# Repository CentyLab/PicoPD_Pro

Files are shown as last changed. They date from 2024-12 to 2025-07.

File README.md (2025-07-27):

# PicoPD Pro
Pico PD Pro is a development board for USB Power Delivery development with Raspberry Pi Pico footprint. The board can help you negotiate voltage from USB PD 3.1 with PPS (programable power supply) and AVS (Adjustable Voltage Supply) up to 5A of current at 30V max. The board feature input current/voltage/temperture reading as well as power switch to cut of the current to external devices. The 30V voltage limit is the max input voltage of the AP33772S IC.

# Quick links
[AP33772S Cpp Library](https://github.com/CentyLab/AP33772S-Cpp)

[AP33772S CircuitPython Library](https://github.com/hansendc/CircuitPython_AP33772s/) -> Big thanks to [@hansendc](https://github.com/hansendc)

[PicoPD Pro Pinout](#picopd-pro-pinout)

[Setup for AP33772S objects](#setup-for-AP33772S-objects)

[Basic AP33772S functions](#basic-ap33772S-functions)

[Important note](#important-note)

[Arduino IDE setup](#arduino-ide-setup)

[VSCode PlatformIO setup](#vscode-platformio-setup)

[Enable Serial print for debugging](#enable-serial-debug)

# PicoPD Pro Pinout
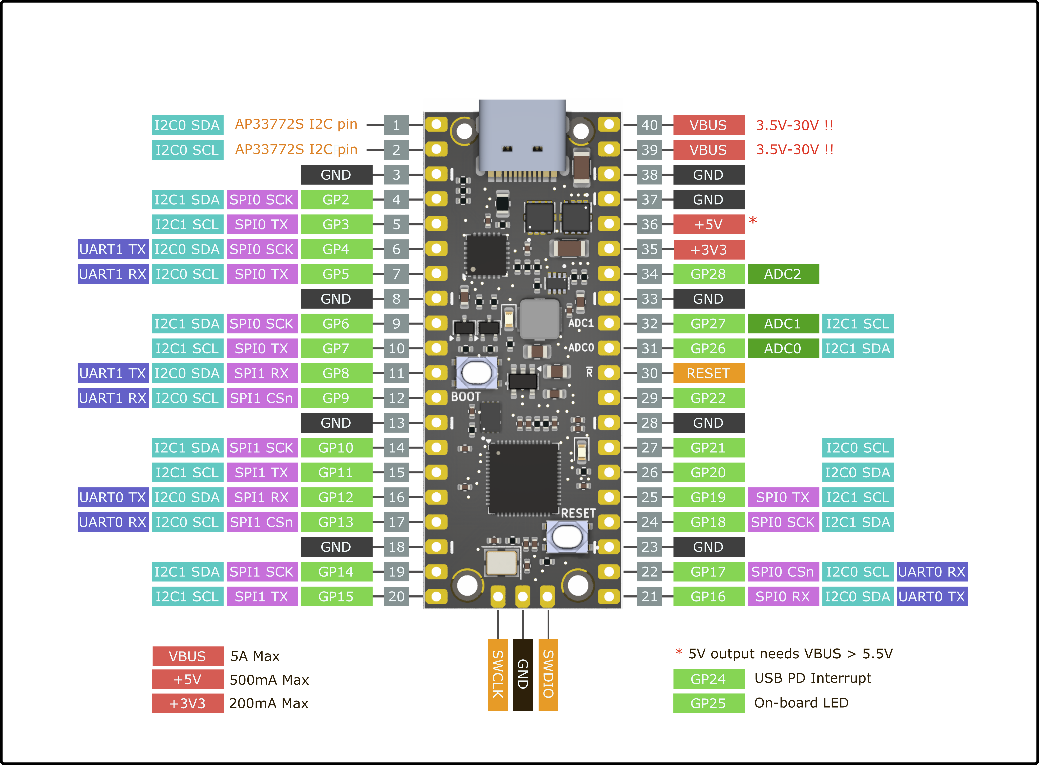
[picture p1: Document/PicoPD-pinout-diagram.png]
pinout


# Setup for AP33772S objects
To use AP33772 IC with the library, first you need to create a `usbpd` object. Then set up your I2C pins and start collecting the power profiles from your charger. Ensure your delay after `Wire.begin()` is more than 500ms for stable PDOs request. Enable pin 23 to allow VBUS pass-through.
```
AP33772S usbpd; // Automatically wire to Wire0

void setup()
{
  Wire.setSDA(0); // Set the correct SDA0 pin
  Wire.setSCL(1); // Set the correct SCL0 pin
  Wire.begin();
  Serial.begin(115200);
  delay(1000); 		// Delay is needed for the IC to obtain PDOs
  usbpd.begin(); 	// Start pulling the PDOs from power supply

  pinMode(25, OUTPUT); // Built in LED

  usbpd.printPDO(); //Print out PDO to Serial port
  usbpd.setOutput(0); // Turn off output switch
}
```

# Basic AP33772S functions
Common functions are:
```
displayProfiles(); //Print out PDOs in Serial
mapPPSAVSInfo();
setFixPDO(int pdoIndex, int max_current);
setPPSPDO(int pdoIndex, int target_voltage, int max_current);
setAVSPDO(int pdoIndex, int target_voltage, int max_current);
setOutput(uint8_t flag);

readVoltage();      //Return voltage in mV
readCurrent();      //Return current in mA      
readTemp();         //Return temperature in C                          
```

# Important note

Calling `usbpd.displayProfiles()` without `Serial.begin()` can soft-brick your PicoPD. Causing the IC to be non-recognizable by your computer. You will have to use PicoProbe to reflash the chip. Check out @Patronics [PicoProbePCB](https://github.com/Patronics/PicoProbePCB) if you would like to make a stable fixture for firmware debugging.

If you want to use PicoPD Pro as an AP33772S evalulation board with your own micro-controller, flash the board with **AP33772S_Eval.uf2** using the drag and drop method. This firmware will config GP0 and GP1 as INPUT to prevent I2C interferance with your own add on micro-controller like ESP32 or STM32.

# Enable Serial Debug

To enable Serial debug, there are 2 main methods:

**Using USB-C Power/Data splitter (easiest):** Use a USB-C Splitter that separates the USB 2.0 signal into another USB-C port. You only need USB 2.0 FullSpeed (12Mbps) for the job, but never hurts to get extra speed if needed later. 

* [USB-C Power/Data Splitter](https://lectronz.com/products/usb-c-splitter) (USB-HighSpeed)
* [USB-C PD Power Splitter](https://www.tindie.com/products/essenceeng/usb-c-pd-power-splitter/) (USB-HighSpeed)

**Using UART communication**: Make sure you are not using GP0 and GP1 as they are reserved for I2C0 channel for AP33772 IC. Check out Youtube tutorial: [Talk to Your Pico Over Serial](https://www.youtube.com/watch?v=pbWhoJdYA1s)

# Arduino IDE setup
Open Arduino IDE, select File -> Preference
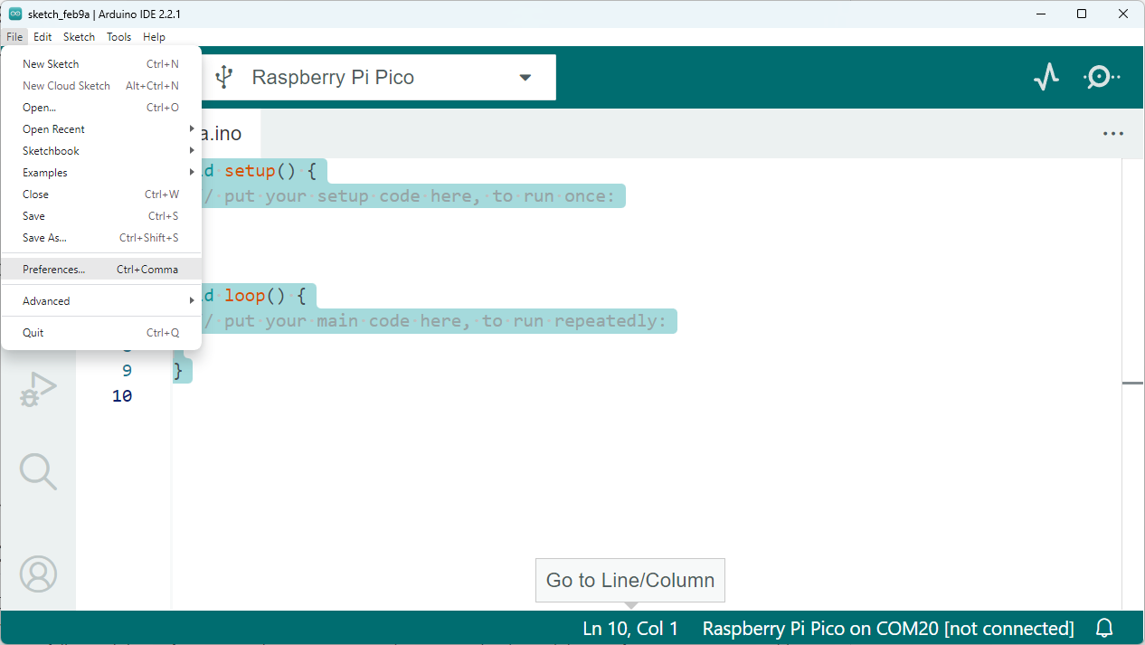
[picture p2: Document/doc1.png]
Preference


Copy this line below and place in "Aditional Boards Manager URLs" -> OK. This will allow you to pull the Earlephilhower Pico core that work with the AP33772 library.

```
https://github.com/earlephilhower/arduino-pico/releases/download/global/package_rp2040_index.json
```
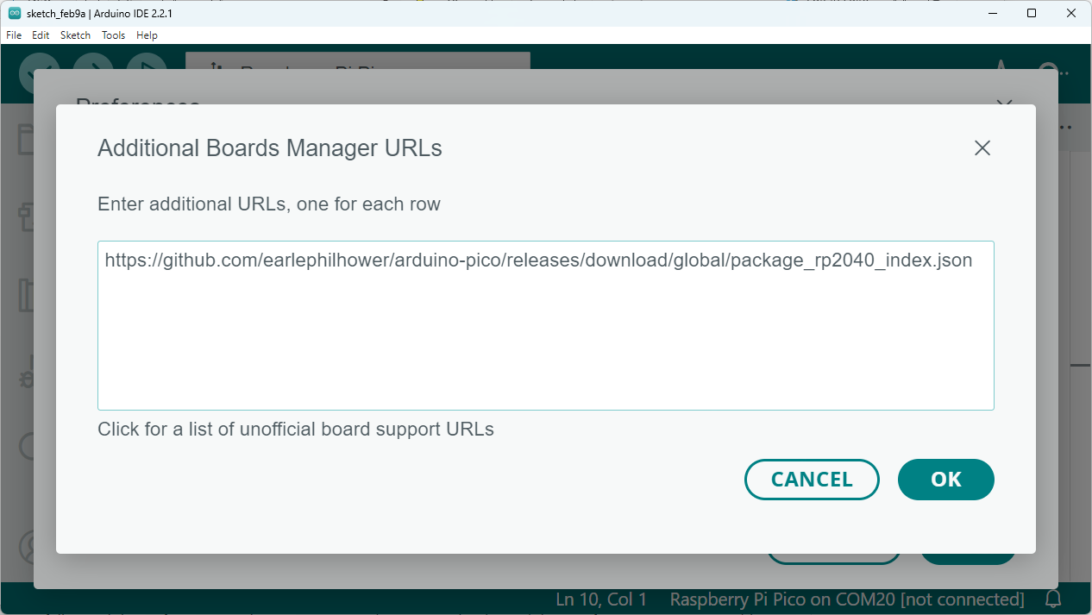
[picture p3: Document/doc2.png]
boardmanagerURL


From Board Manager, search for "Pico" and install the "Raspberry Pi Pico/RP2040" core by Earlephilhower

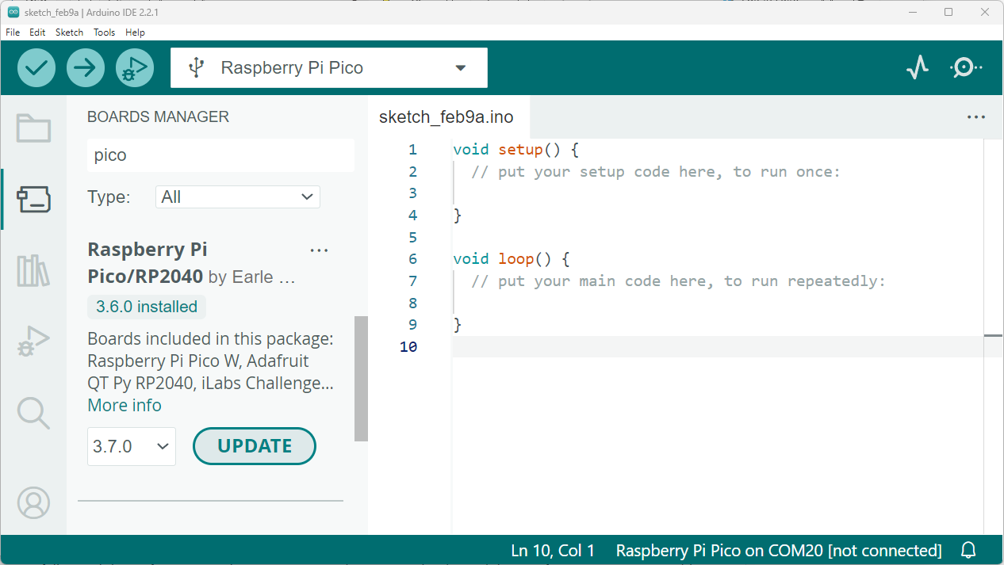
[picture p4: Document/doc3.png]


Now from Tool -> Board -> Raspberry Pi Pico/RP2040 -> Raspberry Pi Pico

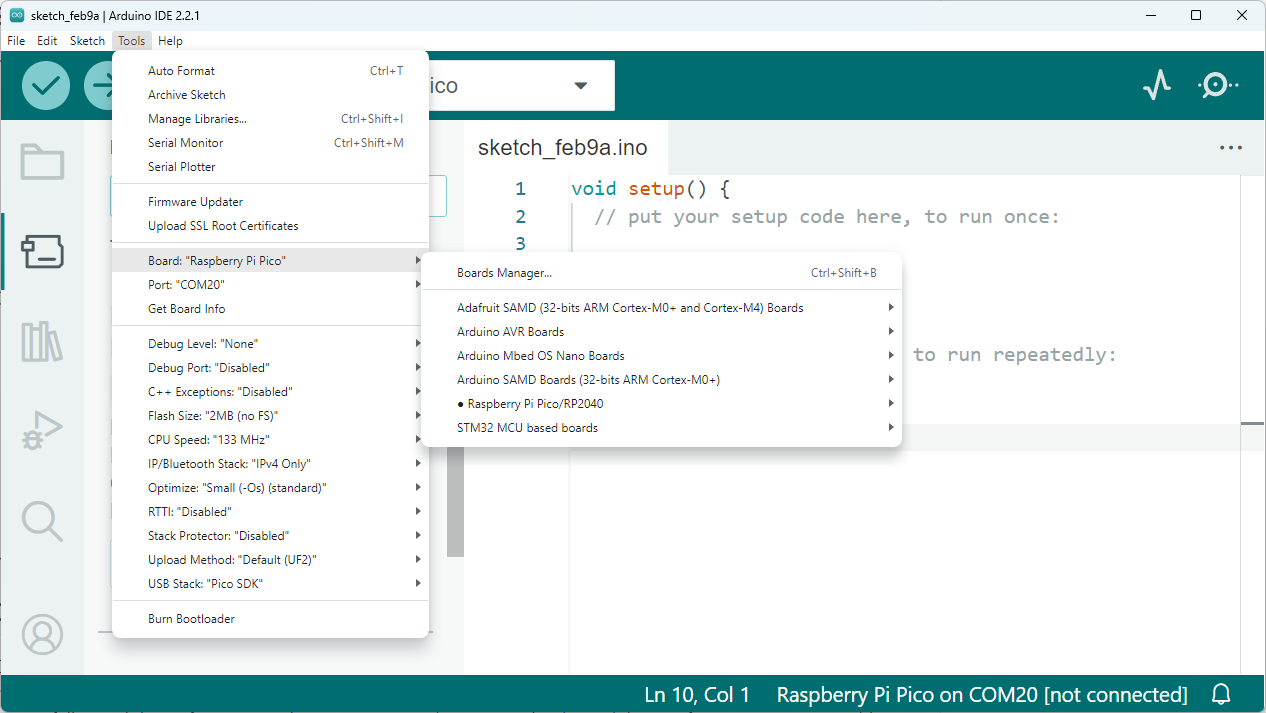
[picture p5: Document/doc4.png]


Now download the latest AP33772 library as a Zip file

```
https://github.com/CentyLab/AP33772S-Cpp
```
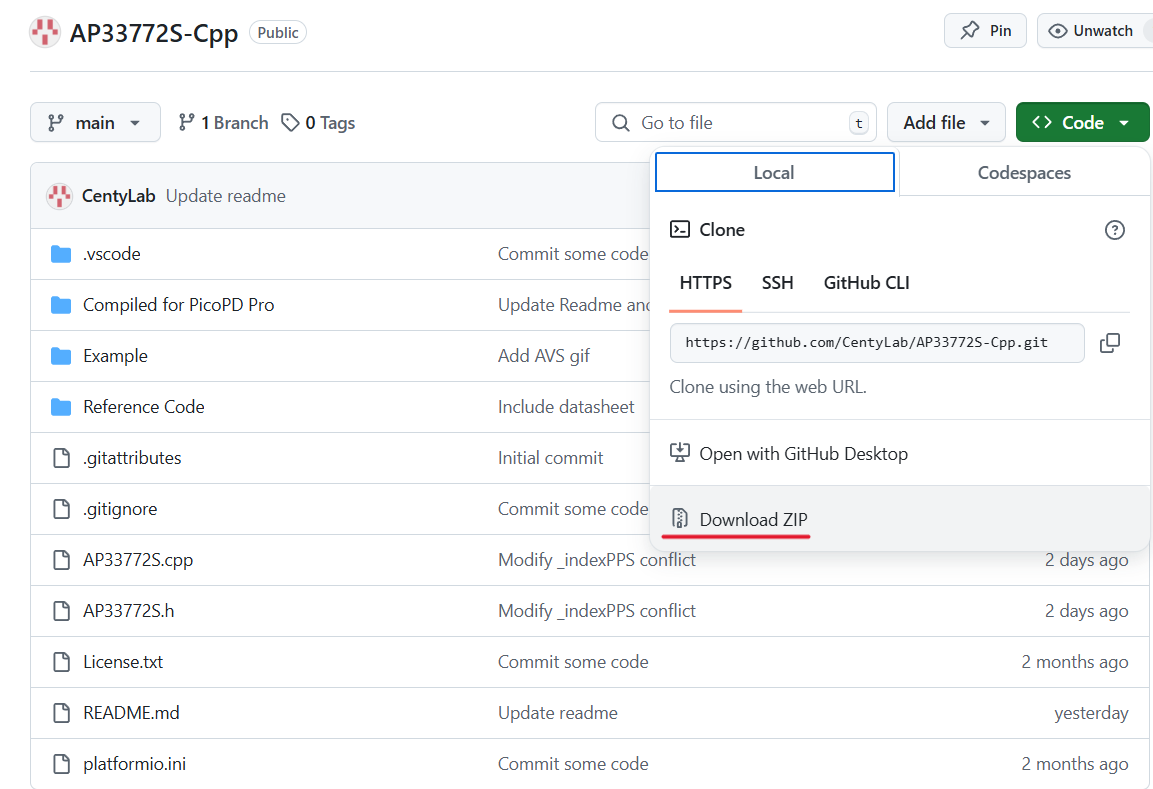
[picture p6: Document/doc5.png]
ap33772lib


Import the AP33772S library into your Arduino IDE. Sketch -> Include library -> Add .ZIP Library ...

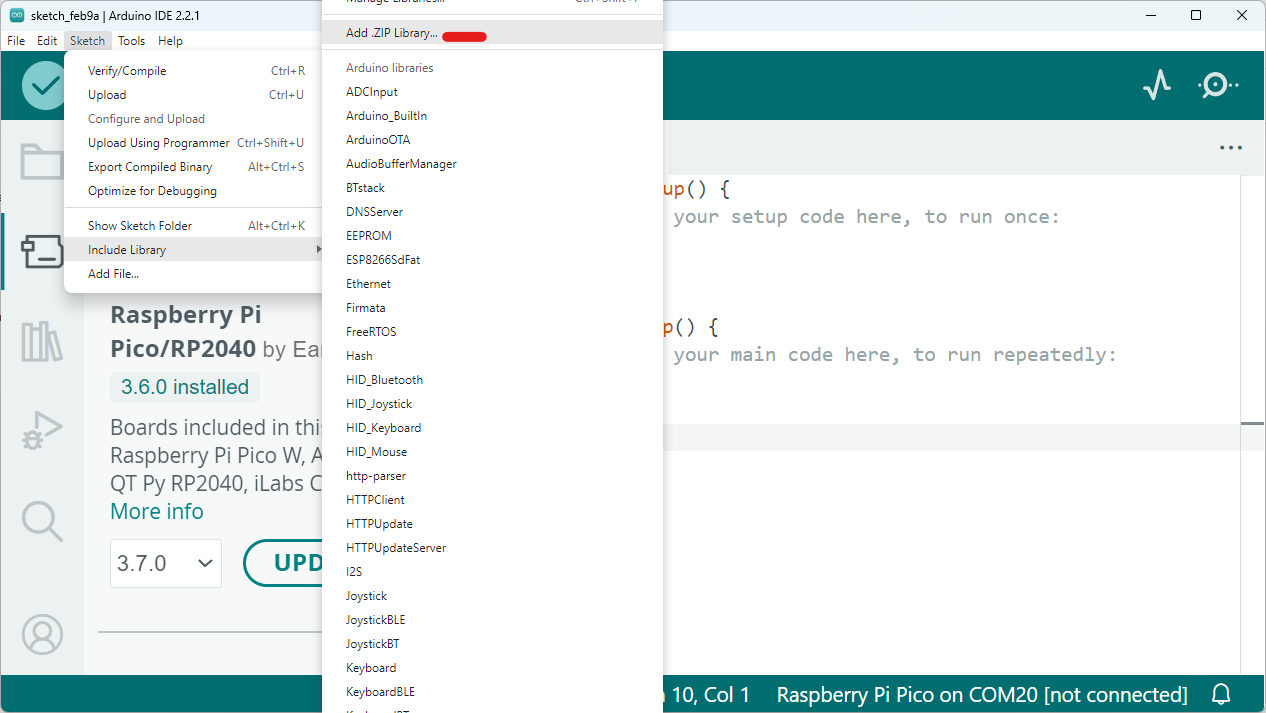
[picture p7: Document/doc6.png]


Now you start using the Example code in File -> Examples -> AP33772-Cpp-main. The example is ready to compile and flash on to your PicoPD.
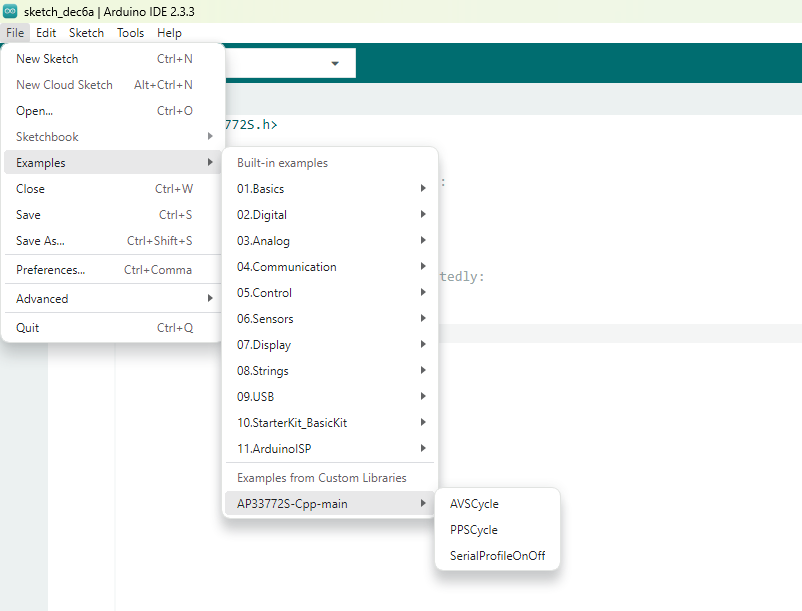
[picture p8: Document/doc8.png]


Now you can plug in your USB-C cable with Power Delivery 2.0/3.0/3.1. If you also like to have serial print out, check out [Enable Serial print for debugging](#enable-serial-debug).

# VSCode PlatformIO setup
After [VSCode](https://code.visualstudio.com/) installation, you will need to install PlatformIO extension.

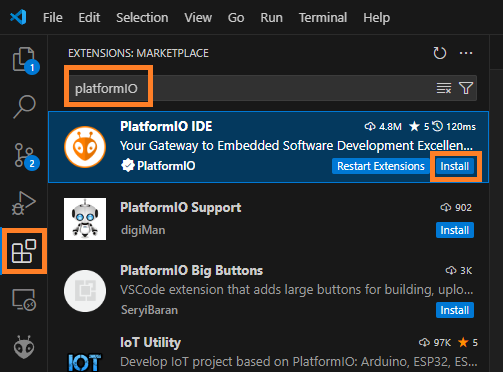
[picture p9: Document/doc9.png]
installplatform


Now create a new PlatformIO project
+ Name:WhatEverYouWantToCallit
+ Board: Pico (RasberryPi)
+ Framework: Arduino (default)

Click "Finish"

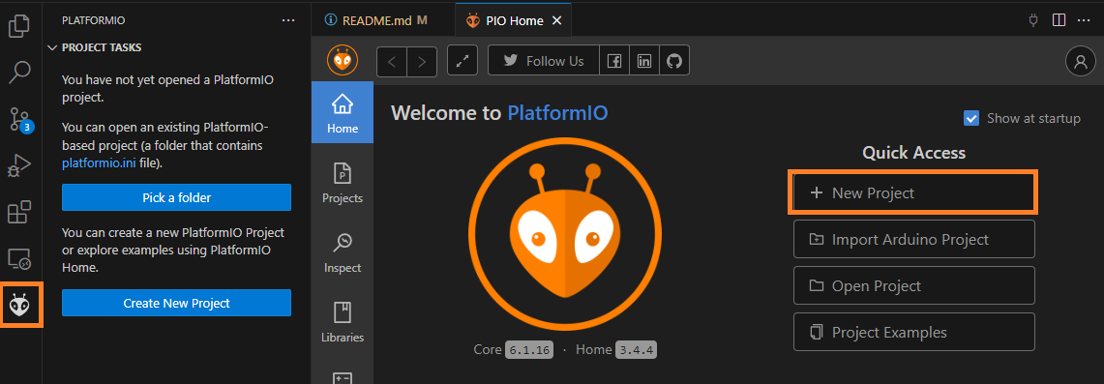
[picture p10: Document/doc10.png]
newproject


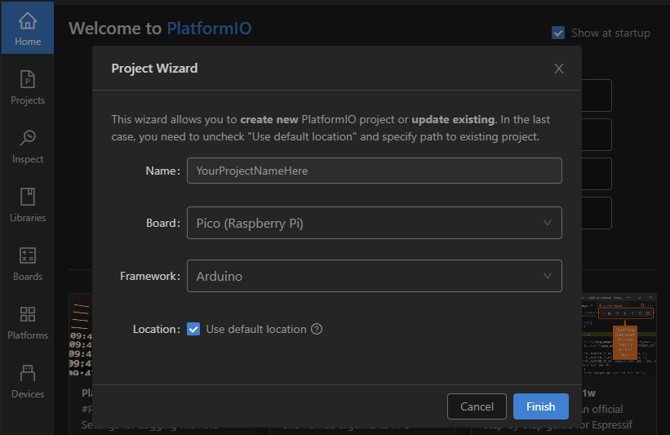
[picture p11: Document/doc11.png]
boardandframework


In your new project, copy this and replace everything in platformio.ini. This is how you ask PlatformIO to compile using Earlephilhower Pico core, and enable upload via USB.

```
[env:pico]
platform = https://github.com/maxgerhardt/platform-raspberrypi.git
board = pico
framework = arduino
board_build.core = earlephilhower

;; If directly upload from PC
upload_protocol = picotool
```

Now download the latest AP33772 library as a Zip file. Unzip and place the folder in `lib`

```
https://github.com/CentyLab/AP33772S-Cpp
```

ap33772lib

Your lib folder should look like this

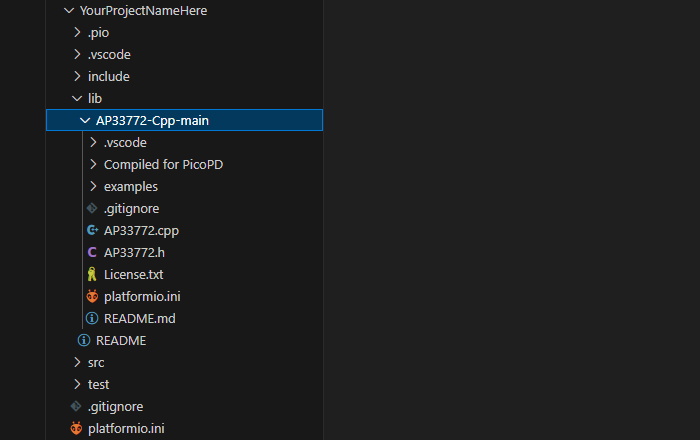
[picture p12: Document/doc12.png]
libstructur


To try out example code, you copy the content inside `lib/Compiled for PicoPD/PPSCycling/PPSCycling.ino`, And replace everything in your `src/main.cpp`

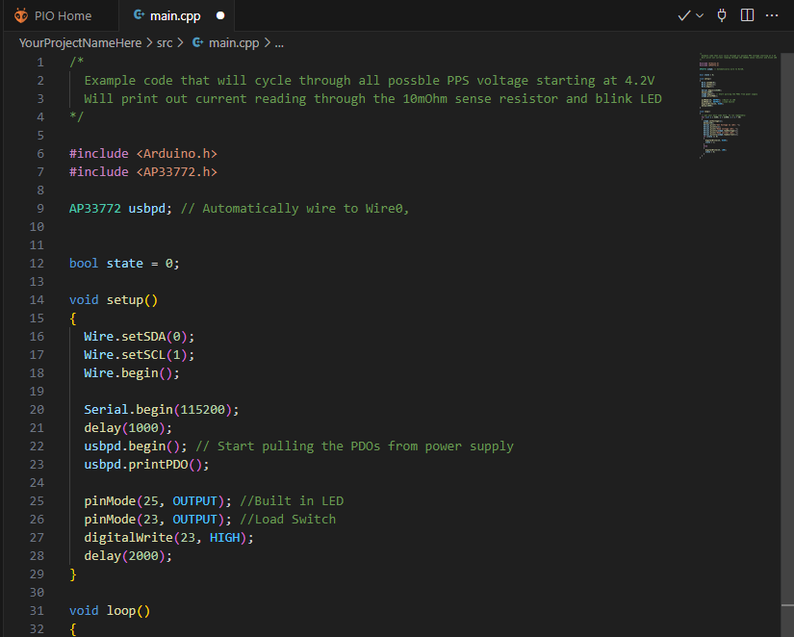
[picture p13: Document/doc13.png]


Now you can plug the PicoPD to your computer via USB-C and hit the upload button. After this, you will have to connect a charger to PicoPD to see the voltage cycling example. If you also like to have serial print out, check out [Enable Serial print for debugging](#enable-serial-debug).

maincpp

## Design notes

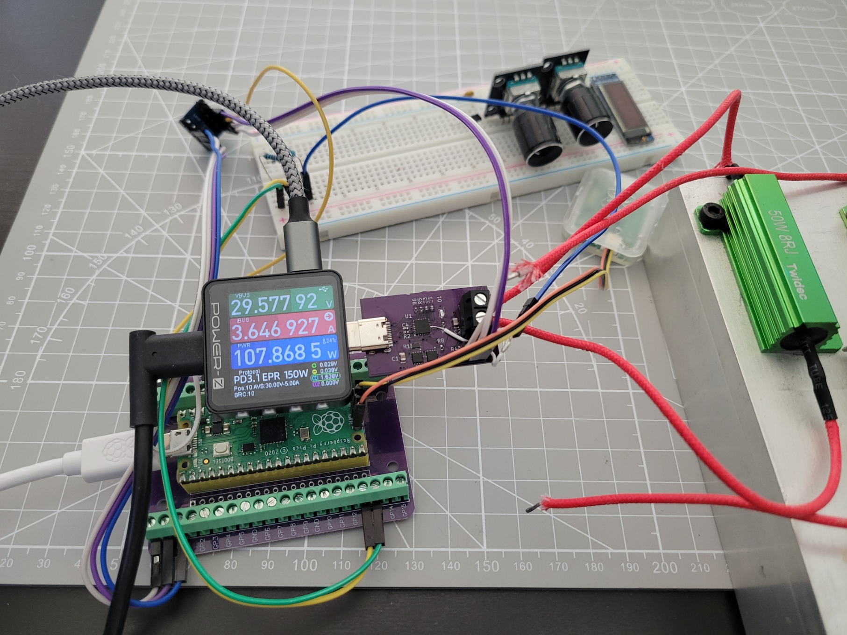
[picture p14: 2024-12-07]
Document/Media/29V3.6ATest.jpg

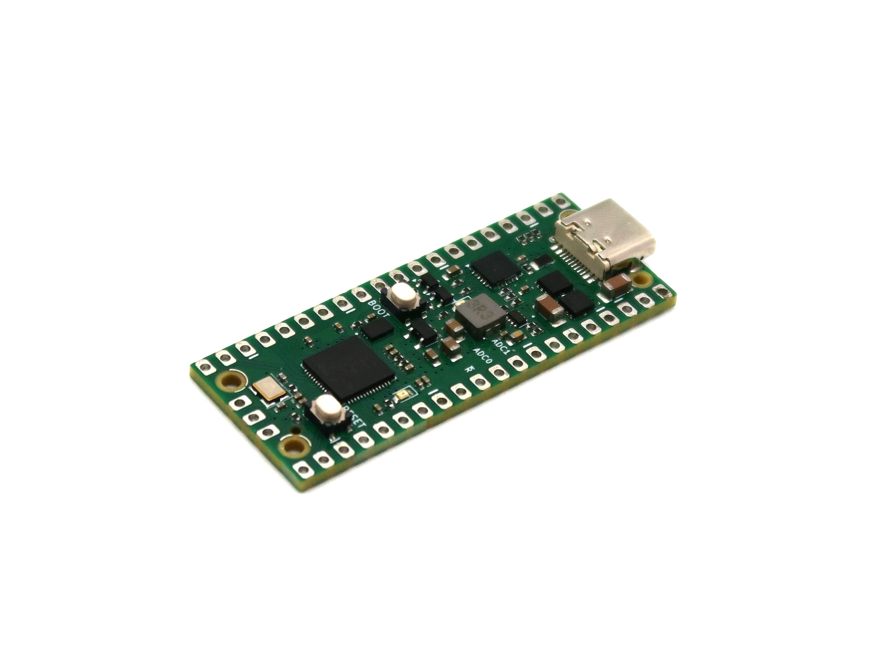
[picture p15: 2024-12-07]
Document/Media/Front.JPG

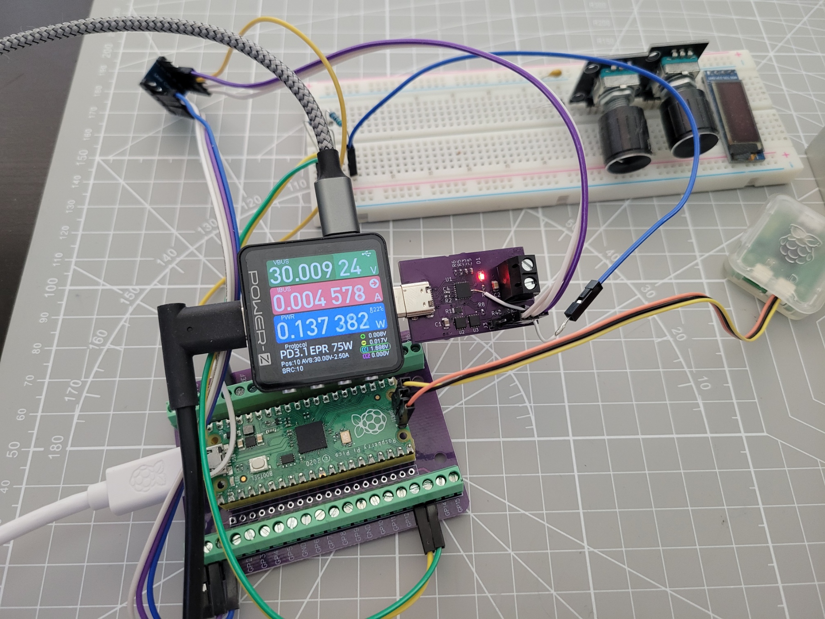
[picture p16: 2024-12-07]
Document/Media/30V request.jpg

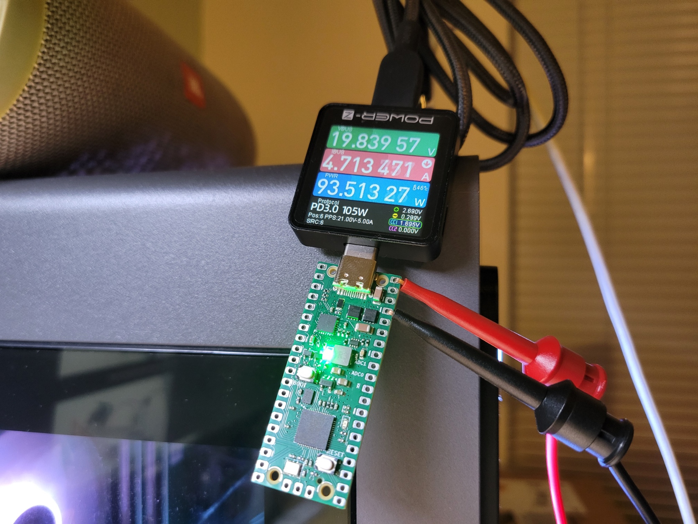
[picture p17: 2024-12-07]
Document/Media/5A pulling.jpg

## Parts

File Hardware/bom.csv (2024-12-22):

Designator | Footprint | Quantity | Value | LCSC Part #
C1, C24 | 0603 | 2 | 1u | C15849
C10, C11, C12, C14, C15, C16, C17, C19, C2, C3, C6, C9 | 0402 | 12 | 100nF | C1525
C13, C18 | 0402 | 2 | 2.2uF | C12530
C20, C25 | 0805 | 2 | 22u | C45783
C23 | 0603 | 1 | 33n | C21117
C4, C5 | 1206 | 2 | 10u | C513774
C7, C8 | 0402 | 2 | 30pF | C1570
D1, D2 | 0603 | 2 | GREEN | C12624
J1 | USB_C_GSwitch | 1 | USB_C_Receptacle_USB2.0_16P | C963411
L1 | L_Wuerth_MAPI-4020 | 1 | 3.3u | C5349667
Q1, Q2 | SOT-323_SC-70 | 2 | BSS138 | C383201
R1, R19, R2, R21, R3, R4, R5, R6 | 0402 | 8 | 5.1k | C25905
R10, R14, R18, R20, R9 | 0402 | 5 | 10k | C25744
R11, R12, R16 | 0402 | 3 | 27R | C138021
R13, R15, R8 | 0402 | 3 | 1k | C11702
R17 | 0402 | 1 | 52.3k | C103091
R7 | 0805 | 1 | 5m | C728267
TH1 | 0402 | 1 | Thermistor_NTC | C77131
U1 | QFN-24-1EP_4x4mm_P0.5mm_EP2.6x2.6mm | 1 | AP33772S | C9900152998
U10 | SOT583 | 1 | TPS62933DRLR | C3200405
U3 | 8-USON | 1 | W25Q16JVUXIQ_TR | C2843335
U4 | QFN-56-1EP_7x7mm_P0.4mm_EP3.2x3.2mm | 1 | RP2040 | C2040
U5, U6 | DFN-8(3.3x3.3) | 2 | AON7262E | C176755
U7 | SOT-23-5 | 1 | AP2204K-3.3 | C112032
U8, U9 | Button_3.2x2.5 | 2 | ~ | C221896
Y1 | Crystal_SMD_3225-4Pin_3.2x2.5mm | 1 | 12MHz | C133334

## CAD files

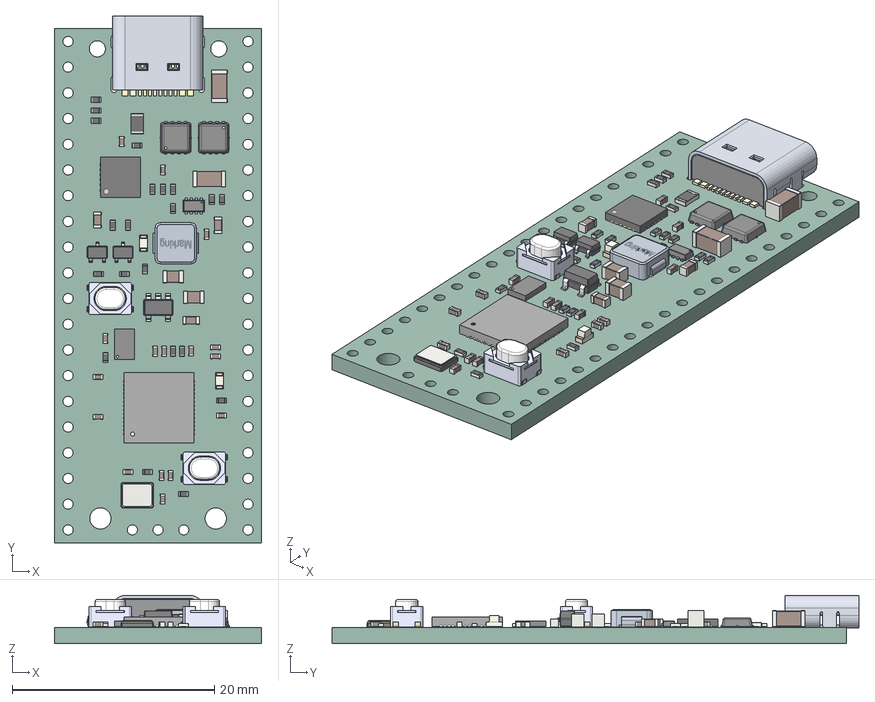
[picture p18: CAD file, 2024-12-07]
Hardware/PicoPD Pro.step
20.5 x 52.1 x 4.75 mm
R_0402_1005Metric x 21
QFN_56_1EP_7x7mm_P04mm_EP32x32mm
C_0402_1005Metric x 16
SOT_323_SC_70 x 2
C_0805_2012Metric x 2
SOT_23_5
C_0603_1608Metric x 3
C_1206_3216Metric x 2
AONR21321 x 2
LED_0603_1608Metric x 2
W25X40CLUXIG TR
QFN-24-1EP_4x4mm_Pitch0.5mm
R_0805_2012Metric
USB Type C Port (SMD Type)
TPS2116DRLR
PTS810SJK250SMTR LFS x 2
Crystal_SMD_3225-4Pin_3.2x2.5mm
Hardware_PCB

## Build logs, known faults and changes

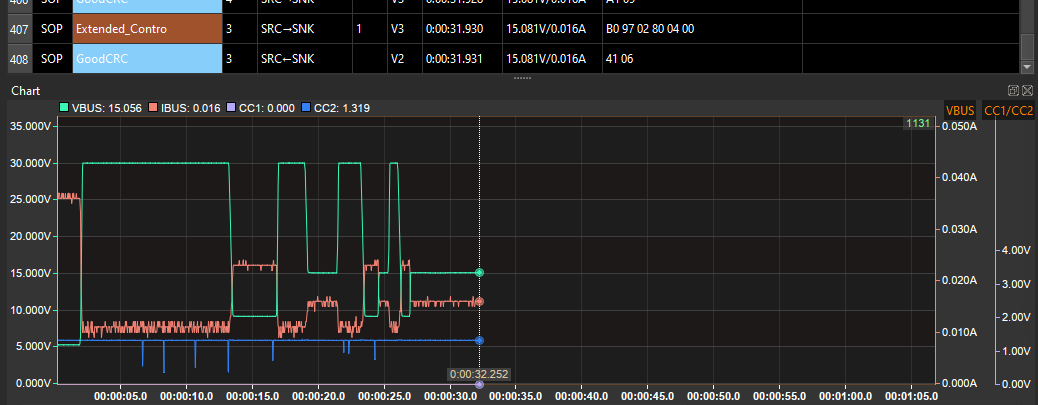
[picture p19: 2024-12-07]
Document/Media/AVSandFix chart.png

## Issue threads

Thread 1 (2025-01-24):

CircuitPython implementation

hansendc, 2025-01-24:
Hi Folks,

The PicoPD and breakout board are awesome! I originally wanted to use the breakout board with an existing CircuitPython microcontroller, so I wrote a little library for the AP33772s:

https://github.com/hansendc/CircuitPython_AP33772s/

It would be awesome if you wanted to either incorporate that code into your repo or link over to to mine.  FWIW, I also noticed that the PicoPD works great with the CircuitPython images for the plain Raspberry Pi Pico. CircuitPython is a great complementary alternative to the Arduino universe.

Thanks for creating the PicoPD. It's *exactly* the hardware I needed for my little project.

CentyLab, 2025-01-24:
Hi Hansendc,

Thank you so much for porting this over. We have never used circuit python
before so this will give us a good base to also port over the older version
of the IC.
Lets us review for a couple of day and we are more than happy to add your
code as submodule in the repo.

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

hansendc, 2025-01-24:
There is some existing Python code for the AP33772:

https://github.com/charkster/AP33772_I2C/blob/main/AP33772.py

I actually started with that code for the AP33772s, but I ended up moving away from it mostly because I found the adafruit_register interfaces so nice to work with. But it might be something to try!

CentyLab, 2025-01-24:
I have added it to our repo. Thank you for your contribution!

Closed 2025-01-24.

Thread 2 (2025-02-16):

DN & DP of AP33772S not connected to Type-C connector

OE4DEA, 2025-02-16:
Hi,
I noticed that you created labels for DN & DP of the AP33772S, but they are not connected to the Type-C connector.
Could you explain the reason for this design choice?
Thanks!

CentyLab, 2025-02-18:
Hi @OE4DEA,

This design decision was an oversight from our team. We weren't sure if the DP+DN moisture detection feature would impact the data flow as this is one of the only two way to program the RP2040 IC. So the team has prioritize signal integrity and programmability for the RP2040.

CentyLab, 2025-04-15:
We are reported from other developer that connecting DN and DP from USB-C to both the AP33772S and micro-controller break USB2.0 connection. Cutting trace to the AP33772S resolve the issue.
We think that the AP33772S moisture sensing is mainly for power device application like chargers, drills..., and was not design for actual data line.

OE4DEA, 2025-04-15:
Thank you for the clarification!
I had reached out to the manufacturer several times regarding this topic, but unfortunately never received a response.
I really appreciate your detailed follow-up!

sslupsky, 2025-05-10:
I noticed the same thing in the schematics as well.  For comparison, TI uses the SBU lines for moisture detection.  I wonder if the SBU lines could be used with the AP33772S?

CentyLab, 2025-05-11:
@sslupsky this idea is awesome. The AP33772S said that moisture detection is done by measuring impedance between the pins and GND. As we are in USB-PD mode, the SBU pins should not be operational. We will test it in our RotoPD circuit and circle back on this topic.

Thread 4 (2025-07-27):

Couple of minor documentation details...

joep, 2025-07-27:
Just got a PicoPD Pro and found a couple of little issues as I was looking at/for the documentation. 1. Your github repository  link on Tindie, where I bought it, is broken. 2. Your pin diagram here has pins GP12 and GP13 both labeled as UART0 TX pins.

CentyLab, 2025-07-27:
Thank you for the note, we have updated the links and the pinout

Closed 2025-07-27.

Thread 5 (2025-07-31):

Disabling output on power up?

joep, 2025-07-31:
In my application, I'd rather not have my PICOPD VBUS output enabled on power up but in looking at the AP37772s data sheet it seems the only way to do this is to use the 100msec configuration window the device gives the host after driving the MCU INT pin high during the power up phase. Otherwise, the VBUS output will be enabled. Have I understood this correctly?

As an aside, the green LED is just a power indicator? At first I assumed it was connected to the LED pin of the device but the schematic says otherwise. Curious as to why it wasn't? Seems more useful to me.

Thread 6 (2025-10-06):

PPS negotiation pauses at 11v

Daaargon, 2025-10-06:
When testing out the PPSCycle example script, the voltage increases from 3.3 volts as expected, but seems to max out at 10.98v according to my multimeter. The board also knows it is capping out early as it only reports outputting 11200mv. Additionally, if I manually set the voltage to anything above 11v, such as 15000mv, it only outputs 5v.

This was using a UK UGREEN Nexode 100W 5-Port GaN. I then tried using a UK Lenovo USC C 65w laptop charger which did cycle through all the PPS voltages successfully so I know the board functions correctly.

I have verified that the UGREEN charger does support PPS and can output 20v, but does not seem to be able to output more than 11v with this board.

CentyLab, 2025-10-07:
Hi @Daaargon,
I suspect that the UGREEN charger is having two different PPS profile. We have seen that more often in lower wattage Anker charger. The PPS profile sometime looks like this:
PPS1: 3.3V-11V @ 3A
PPS2: 9V-20V @ 2.25A
The code only grab on to the 1st PPS profile as it was hard coded that way.

Else you can try this. In the PPSCycle code, there is this line 21 in Arduino code:
`usbpd.setPPSPDO(usbpd.getPPSIndex(), i, 3000);`

Change to something like... By incrementing the number, you are searching for that PPS profile index.
`usbpd.setPPSPDO(4, i, 3000);`
or
`usbpd.setPPSPDO(5, i, 3000);`

Best if you can print out the profile of the charger, it will help better debug the issue.

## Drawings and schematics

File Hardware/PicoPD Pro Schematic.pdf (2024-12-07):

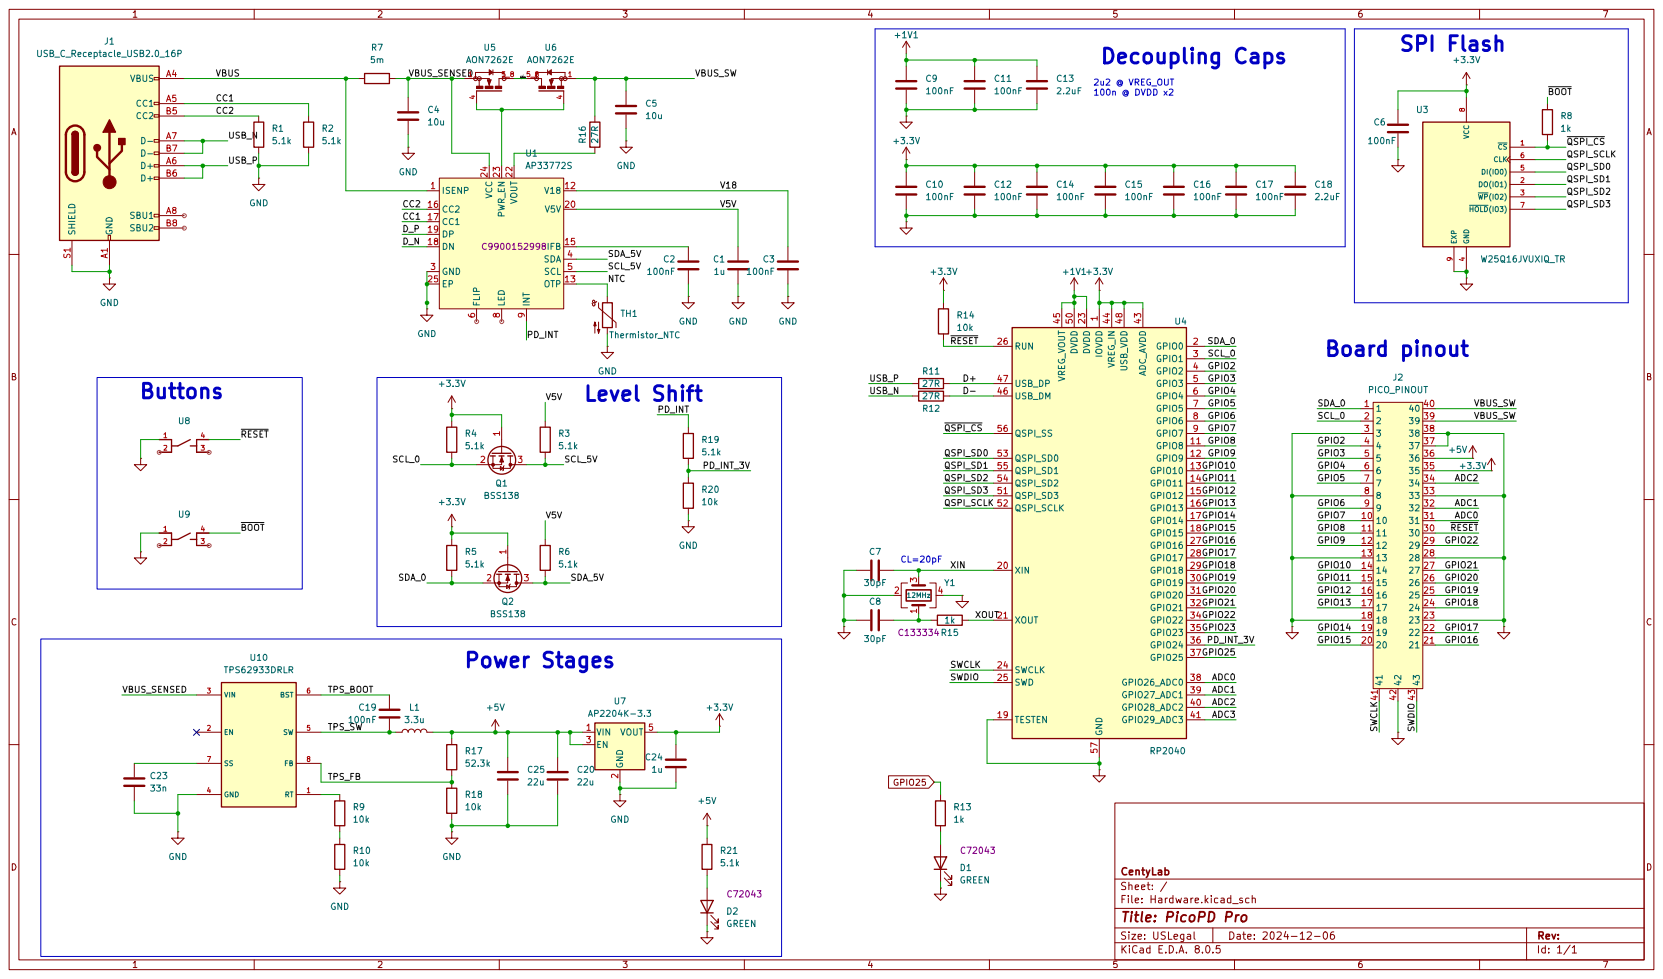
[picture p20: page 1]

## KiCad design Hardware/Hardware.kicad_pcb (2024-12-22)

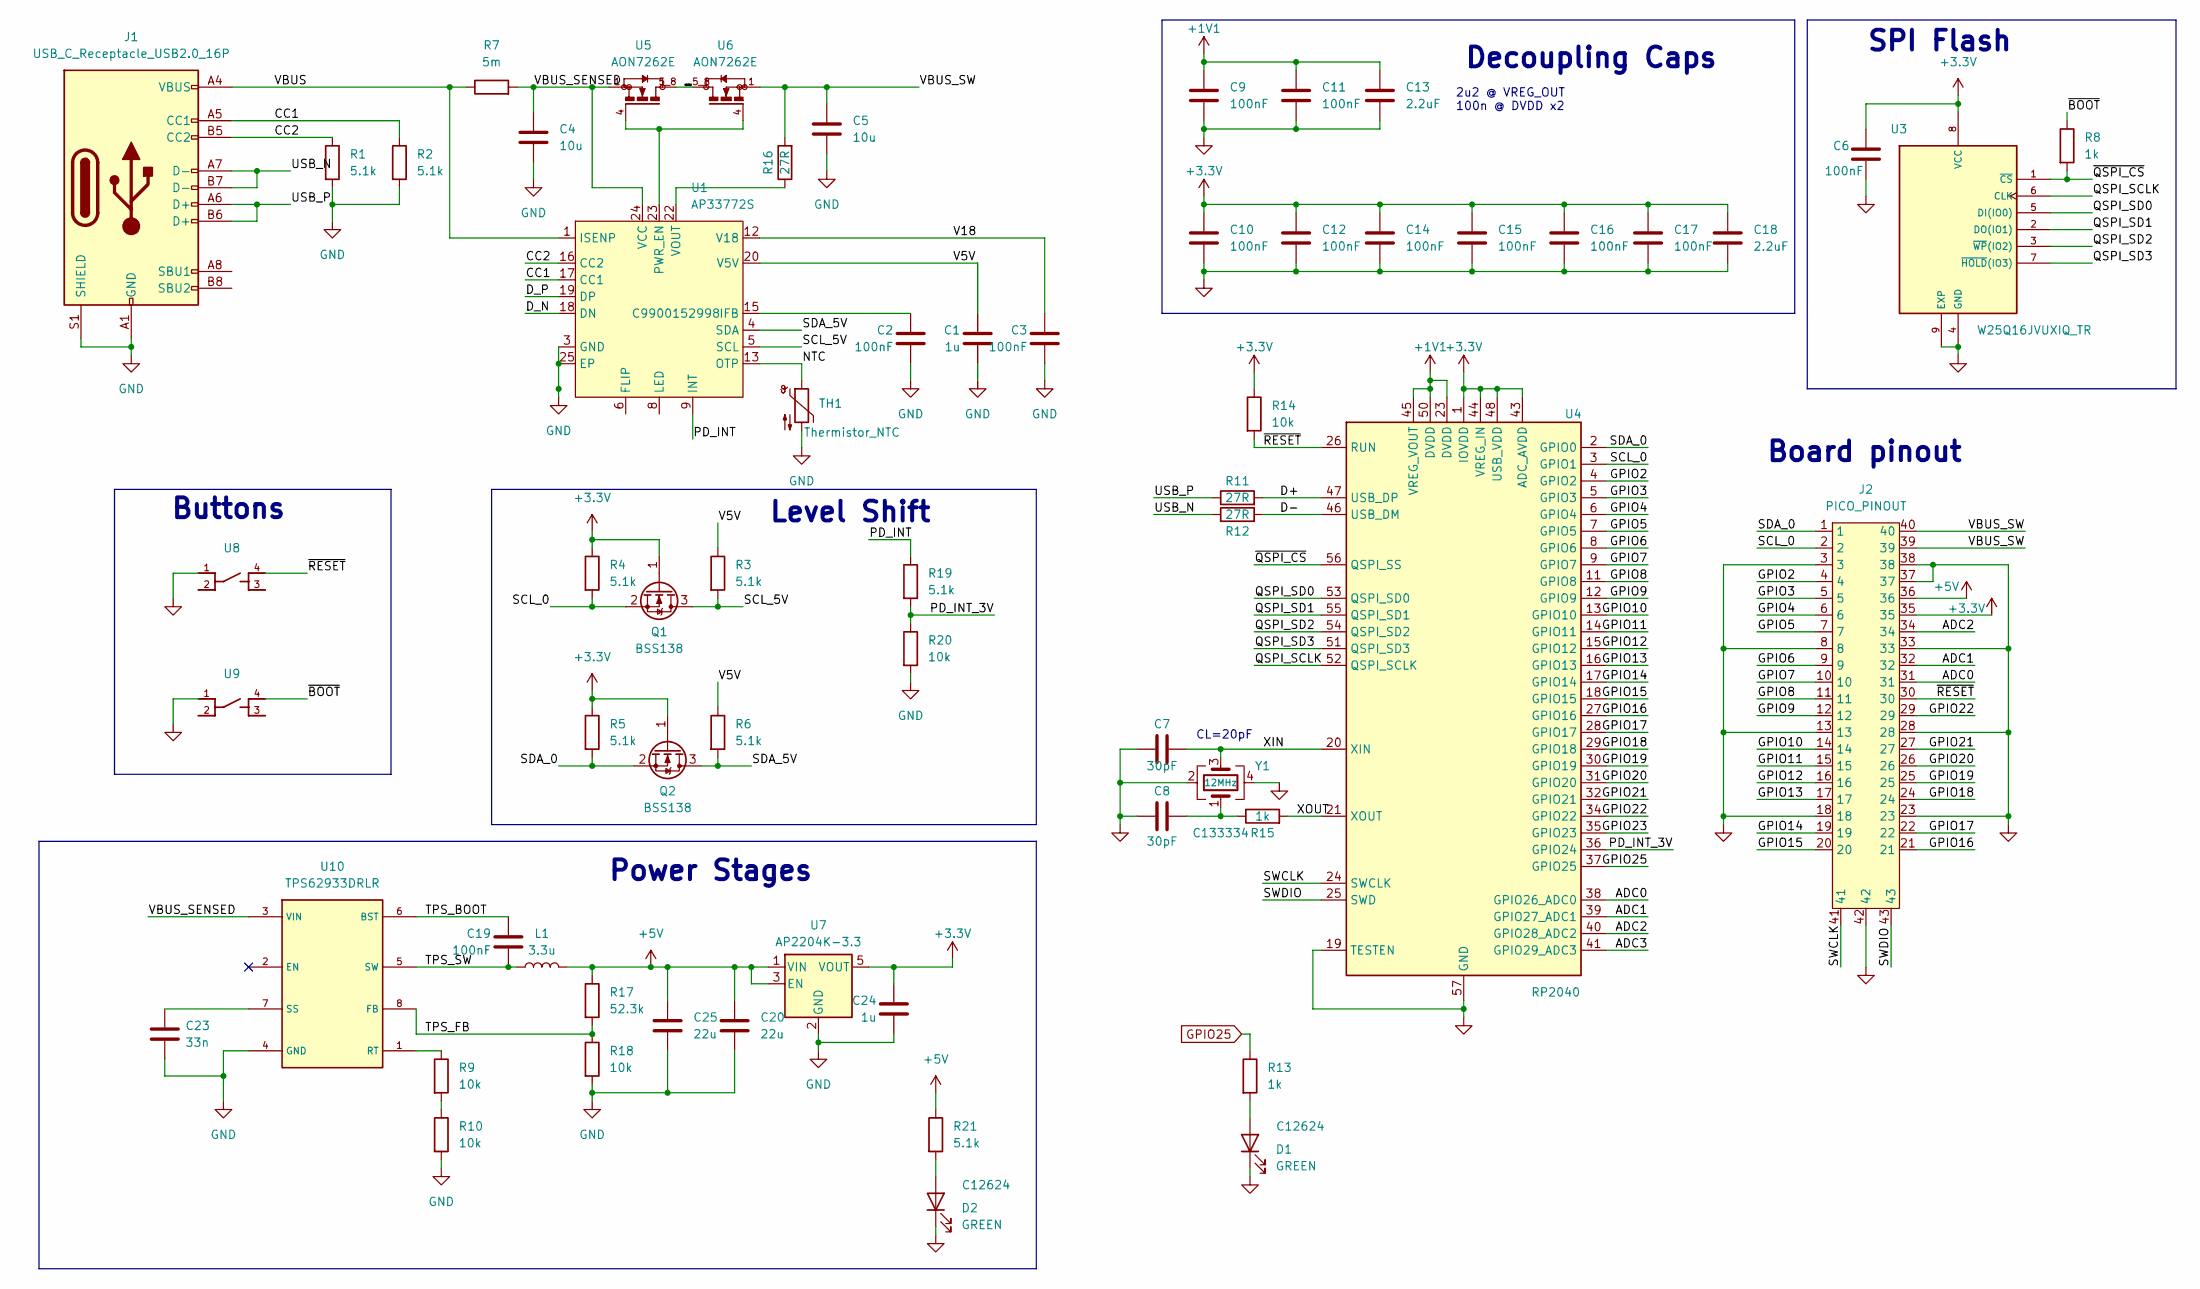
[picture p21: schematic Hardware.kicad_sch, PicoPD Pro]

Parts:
C1, C24: 1u; C_0603_1608Metric; LCSC C15849
C2, C3, C6, C9, C10, C11, C12, C14, C15, C16, C17, C19: 100nF; C_0402_1005Metric; LCSC C1525
C4, C5: 10u; C_1206_3216Metric; LCSC C513774
C7, C8: 30pF; C_0402_1005Metric; LCSC C1570
C13, C18: 2.2uF; C_0402_1005Metric; LCSC C12530
C20, C25: 22u; C_0805_2012Metric; LCSC C45783
C23: 33n; C_0603_1608Metric; LCSC C21117
D1, D2: GREEN; LED_0603_1608Metric; LCSC C12624
J1: USB_C_Receptacle_USB2.0_16P; USB_C_GSwitch; LCSC C963411
J2: PICO_PINOUT; PicoPD_Pinout
L1: 3.3u; L_Wuerth_MAPI-4020; LCSC C5349667
Q1, Q2: BSS138; SOT-323_SC-70; LCSC C383201
R1, R2, R3, R4, R5, R6, R19, R21: 5.1k; R_0402_1005Metric; LCSC C25905
R7: 5m; R_0805_2012Metric; Part # PA0805FRE470R005L; LCSC C728267
R8, R13, R15: 1k; R_0402_1005Metric; LCSC C11702
R9, R10, R14, R18, R20: 10k; R_0402_1005Metric; LCSC C25744
R11, R12, R16: 27R; R_0402_1005Metric; LCSC C138021
R17: 52.3k; R_0402_1005Metric; LCSC C103091
TH1: Thermistor_NTC; R_0402_1005Metric; LCSC C77131
U1: AP33772S; QFN-24-1EP_4x4mm_P0.5mm_EP2.6x2.6mm; LCSC C9900152998
U3: W25Q16JVUXIQ_TR; 8-USON; PARTREV H; LCSC C2843335
U4: RP2040; QFN-56-1EP_7x7mm_P0.4mm_EP3.2x3.2mm; LCSC C2040
U5, U6: AON7262E; DFN-8(3.3x3.3); LCSC C176755
U7: AP2204K-3.3; SOT-23-5; JLCPCB Rotation Offset 0
U8, U9: Button_3.2x2.5; LCSC C221896
U10: TPS62933DRLR; SOT583; LCSC C3200405
Y1: 12MHz; Crystal_SMD_3225-4Pin_3.2x2.5mm; LCSC C133334

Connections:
+1V1: C9.1, C11.1, C13.1, U4.23 (DVDD), U4.45 (VREG_VOUT), U4.50 (DVDD)
+3.3V: C6.1, C10.1, C12.1, C14.1, C15.1, C16.1, C17.1, C18.1, C24.1, J2.35, Q1.1 (G), Q2.1 (G), R4.1, R5.1, R14.1, U3.8 (VCC), U4.1 (IOVDD), U4.10 (IOVDD), U4.22 (IOVDD), U4.33 (IOVDD), U4.42 (IOVDD), U4.43 (ADC_AVDD), U4.44 (VREG_IN), U4.48 (USB_VDD), U4.49 (IOVDD), U7.5 (VOUT)
+5V: C20.1, C25.1, J2.36, L1.2, R17.1, R21.1, U7.1 (VIN), U7.3 (EN)
/ADC0: J2.31, U4.38 (GPIO26_ADC0)
/ADC1: J2.32, U4.39 (GPIO27_ADC1)
/ADC2: J2.34, U4.40 (GPIO28_ADC2)
/ADC3: U4.41 (GPIO29_ADC3)
/CC1: J1.A5 (CC1), R2.1, U1.17 (CC1)
/CC2: J1.B5 (CC2), R1.1, U1.16 (CC2)
/D+: R11.2, U4.47 (USB_DP)
/D-: R12.2, U4.46 (USB_DM)
/D_N: U1.18 (DN)
/D_P: U1.19 (DP)
/GPIO2: J2.4, U4.4 (GPIO2)
/GPIO3: J2.5, U4.5 (GPIO3)
/GPIO4: J2.6, U4.6 (GPIO4)
/GPIO5: J2.7, U4.7 (GPIO5)
/GPIO6: J2.9, U4.8 (GPIO6)
/GPIO7: J2.10, U4.9 (GPIO7)
/GPIO8: J2.11, U4.11 (GPIO8)
/GPIO9: J2.12, U4.12 (GPIO9)
/GPIO10: J2.14, U4.13 (GPIO10)
/GPIO11: J2.15, U4.14 (GPIO11)
/GPIO12: J2.16, U4.15 (GPIO12)
/GPIO13: J2.17, U4.16 (GPIO13)
/GPIO14: J2.19, U4.17 (GPIO14)
/GPIO15: J2.20, U4.18 (GPIO15)
/GPIO16: J2.21, U4.27 (GPIO16)
/GPIO17: J2.22, U4.28 (GPIO17)
/GPIO18: J2.24, U4.29 (GPIO18)
/GPIO19: J2.25, U4.30 (GPIO19)
/GPIO20: J2.26, U4.31 (GPIO20)
/GPIO21: J2.27, U4.32 (GPIO21)
/GPIO22: J2.29, U4.34 (GPIO22)
/GPIO23: U4.35 (GPIO23)
/NMOS: U5.5_8, U6.5_8
/NTC: TH1.1, U1.13 (OTP)
/PD_INT: R19.1, U1.9 (INT)
/PD_INT_3V: R19.2, R20.1, U4.36 (GPIO24)
/QSPI_SCLK: U3.6 (CLK), U4.52 (QSPI_SCLK)
/QSPI_SD0: U3.5 (DI(IO0)), U4.53 (QSPI_SD0)
/QSPI_SD1: U3.2 (DO(IO1)), U4.55 (QSPI_SD1)
/QSPI_SD2: U3.3 (~WP(IO2)), U4.54 (QSPI_SD2)
/QSPI_SD3: U3.7 (~HOLD(IO3)), U4.51 (QSPI_SD3)
/SCL_0: J2.2, Q1.2 (S), R4.2, U4.3 (GPIO1)
/SCL_5V: Q1.3 (D), R3.2, U1.5 (SCL)
/SDA_0: J2.1, Q2.2 (S), R5.2, U4.2 (GPIO0)
/SDA_5V: Q2.3 (D), R6.2, U1.4 (SDA)
/SWCLK: J2.41, U4.24 (SWCLK)
/SWDIO: J2.43, U4.25 (SWD)
/TPS_BOOT: C19.1, U10.6 (BST)
/TPS_FB: R17.2, R18.1, U10.8 (FB)
/TPS_SW: C19.2, L1.1, U10.5 (SW)
/USB_N: J1.A7 (D-), J1.B7 (D-), R12.1
/USB_P: J1.A6 (D+), J1.B6 (D+), R11.1
/V5V: C1.1, R3.1, R6.1, U1.20 (V5V)
/V18: C3.1, U1.12 (V18)
/VBUS: J1.A4 (VBUS), J1.A9 (VBUS), J1.B4 (VBUS), J1.B9 (VBUS), R7.1, U1.1 (ISENP)
/VBUS_SENSED: C4.1, R7.2, U1.24 (VCC), U5.1, U5.2, U5.3, U10.3 (VIN)
/VBUS_SW: C5.1, J2.39, J2.40, R16.2, U6.1, U6.2, U6.3
/XIN: C7.1, U4.20 (XIN), Y1.3
/XOUT: R15.2, U4.21 (XOUT)
/~BOOT: R8.1, U9.4
/~QSPI_CS: R8.2, U3.1 (~CS), U4.56 (QSPI_SS)
/~RESET: J2.30, R14.2, U4.26 (RUN), U8.4
GND: C1.2, C2.2, C3.2, C4.2, C5.2, C6.2, C7.2, C8.2, C9.2, C10.2, C11.2, C12.2, C13.2, C14.2, C15.2, C16.2, C17.2, C18.2, C20.2, C23.2, C24.2, C25.2, D1.1 (K), D2.1 (K), J1.A1 (GND), J1.A12 (GND), J1.B1 (GND), J1.B12 (GND), J1.S1 (SHIELD), J2.3, J2.8, J2.13, J2.18, J2.23, J2.28, J2.33, J2.37, J2.38, J2.42, R1.2, R2.2, R10.2, R18.2, R20.2, TH1.2, U1.2 (NC), U1.3 (GND), U1.7 (NC), U1.10 (NC), U1.11 (NC), U1.14 (NC), U1.21 (NC), U1.25 (EP), U3.4 (GND), U3.9 (EXP), U4.19 (TESTEN), U4.57 (GND), U7.2 (GND), U8.1, U9.1, U10.4 (GND), Y1.2, Y1.4
GPIO25: R13.1, U4.37 (GPIO25)
unnamed: C8.1, R15.1, Y1.1
unnamed: D1.2 (A), R13.2
unnamed: D2.2 (A), R21.2
unnamed: R9.2, R10.1
unnamed: C2.1, U1.15 (IFB)
unnamed: U1.23 (PWR_EN), U5.4, U6.4
unnamed: R16.1, U1.22 (VOUT)
unnamed: R9.1, U10.1 (RT)
unnamed: C23.1, U10.7 (SS)

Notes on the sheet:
Buttons
CL=20pF
SPI Flash
Board pinout
Power Stages
Level Shift
2u2 @ VREG_OUT 100n @ DVDD x2
Decoupling Caps

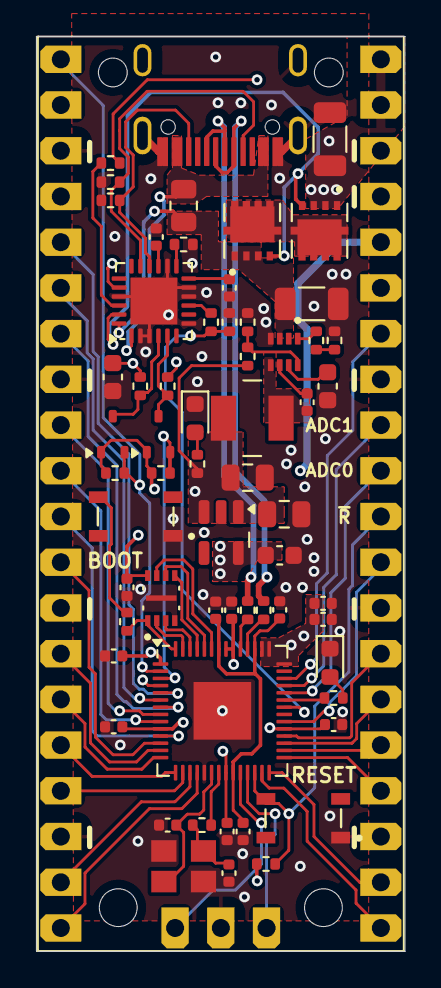
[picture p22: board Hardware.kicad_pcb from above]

Board: 4 copper layers, 20.5 x 50.8 mm, 62 parts (0 on the bottom side), 72 nets.

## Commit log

2024-12-22 Update BOM
    [Hardware.kicad_pcb, Hardware.kicad_sch, bom.csv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]
2025-01-24 Rename folders and add CircuitPython Support
